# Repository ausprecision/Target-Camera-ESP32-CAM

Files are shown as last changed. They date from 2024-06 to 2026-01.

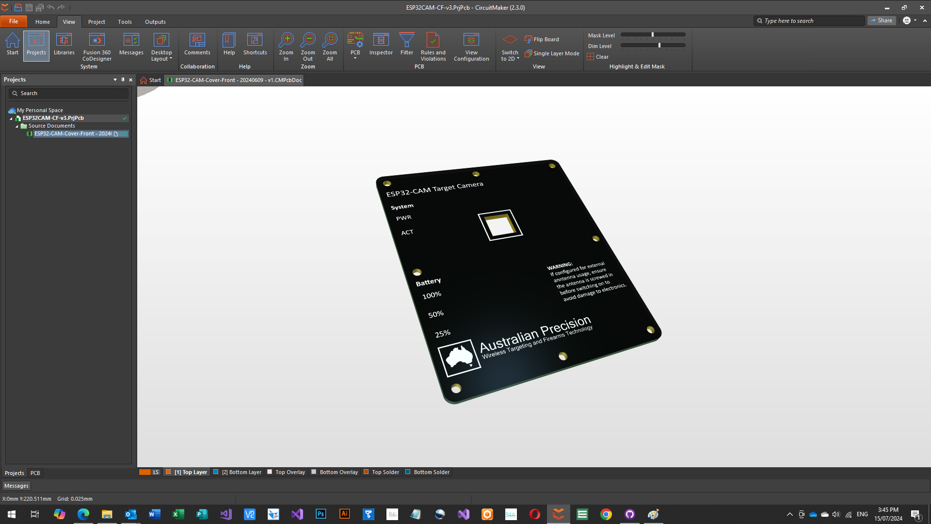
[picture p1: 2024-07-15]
Manufacturing - PCB Design/Image - ESP32-CAM-CF.png

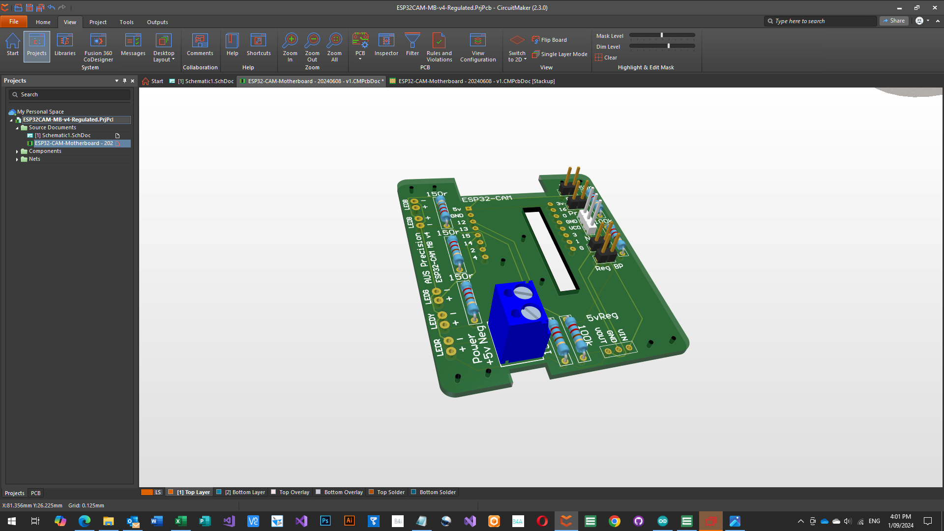
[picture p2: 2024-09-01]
Manufacturing - PCB Design/Image - ESP32-CAM-MB.png

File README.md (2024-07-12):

# Target Camera (ESP32-CAM)
A Wireless Target Camera System based off the ESP32-CAM. A combination of programming languages is used, Arduino IDE for the ESP32-CAM, Windows UWP (Visual Basic) for the client application which also uses an MJPEG library for reading the camera stream. The UWP client application displays the stream and overlays ballistic information.

#### Arduino - IDE code for the ESP32-CAM
- Battery Management - Read ADC (PIN 12) - Prior to WiFi initialization which ties up the ADC inputs on the board.
- Battery Management - Requires a voltage divider, please see the Altium Circuitmaker Schematic and PCB layout.
- OTA / Over The Air Updates - Partition Scheme: "Minimal SPIFFS (1.9MB APP with OTA/190KB SPIFFS).
- SPIFFS partition is small, is primarily used to store config data and a small image file/logo file and favicon.

#### 3D Printing - 3D Printed Parts for the ESP32-CAM Housing/Enclosure
- Main Section - Houses the ESP32-CAM and ESP32-CAM motherboard, light pipes and power switch.
- Battery Section - Houses the battery board and AA battery holder.
- Holder - Anetnna - Part is used for installing the antenna assembly.
- Holder - Nut - Part used for locating/holding the UNC nut for tripods.
- Locating Block - Screwed into the battery board, holds the ESM32-CAM motherboard in place.

Note: Recommend ABS or PETG for 3D Printing due to outdoor use.

#### UWP-Testing-VB - Simple Visual Studio 2022 Application to Read MJPEG Stream from the ESP32-CAM
This application is the testing application for reading the MJPEG stream and displaying it from the ESP32-CAM, please see information below on the required NuGet packages and configuration information. Developed using Microsoft Visual Studio 2022 and Visual Basic.

- NuGet Package - Microsoft.NETCore.UniversalWindowsPlatform - Version 6.1.9
- NuGet Package - MjpegProcessor - Version 1.0.0 - https://github.com/follesoe/MjpegProcessor

Visual Studio 2022 Project Configuration (Visual Basic and C#)
- Target Version - Windows 10, version 2004 (10.0; Build 19041)
- Minimum Version - Windows 10, version 1809 (10.0; Build 17753)

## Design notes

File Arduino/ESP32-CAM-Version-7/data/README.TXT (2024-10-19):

KB Article: AP100001
Product(s): AUS Precision Disk Operating System
Version(s): AP-DOS:1.00
Keyword(s): apdos
Last Modified: 23-SEP-2024
-------------------------------------------------------------------------------
The information in this article applies to:

- AUS Precision AP-DOS Operating System Version 1.00 
-------------------------------------------------------------------------------

SUMMARY
=======

The following information was taken from the AP-DOS 1.00 README.TXT file. This
file is referred to in the AP-DOS1 Concise User's Guide. This file refers to
how AP-DOS interacts with the hardware and software of your ESP32 based target
camera system hardware.

1. HARDWARE COMPATIBILITY WITH AP-DOS
=====================================
1.1 AP-DOS is compatible with any ESP32 based SoC Processor, though is ideally
suited for the ESP32S series processors that are used with various ESP32-CAM
boards from many manufacturers.

1.2 The firmware running AP-DOS uses general purpose input/output (GPIO Pins)
for various functions. These include reading battery levels from the 
analogue to digital converter (ADC) running on the board itself as well as
turning various LED lights on the board on or off.

1.3 Target Camera Systems supplied by AUS Precision run firmware that supports
AP-DOS and also pre-defined GPIO pins for various functions. Other vendors
might be using different GPIO mappings for different hardware functions.

1.4 At the time of this article, the firmware supplied by AUS Precision does
not allow for custom GPIO pin mappings, therefore some AP-DOS functions might
run with problems due to the pin mappings being different. If this is the case
the firmware would need to be manually re-compiled with the correct mappings.

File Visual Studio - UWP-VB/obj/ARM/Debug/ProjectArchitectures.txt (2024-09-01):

C:\Users\david\OneDrive\AUS Precision (GitHub)\Target-Camera-ESP32-CAM\UWP-Testing-VB\UWP-Testing-VB.vbproj;arm

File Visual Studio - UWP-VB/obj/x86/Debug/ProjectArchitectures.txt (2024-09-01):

C:\Users\david\OneDrive\AUS Precision (GitHub)\Target-Camera-ESP32-CAM\Visual Studio - UWP-VB\UWP-Testing-VB.vbproj;x86

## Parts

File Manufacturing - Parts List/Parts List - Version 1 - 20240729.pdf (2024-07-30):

Part Name | Type | Part Detail / Description | QTY Price (EA) Price (Tot.) Used For | Supplier | Supplier Part #
Screw - 4g x 1/2" (2.9 x 12mm) | Fastener | Black Zinc, Countersunk Phillips Self Tapper - ANSI B18.6.4 | 4 | $0.07 | $0.28 | Mounting Main Section to Battery Section | www.boltandnut.com.au | 01C412BZ
Screw - 4g x 1/4" (2.9 x 6.5mm) | Fastener | Black Zinc, Countersunk Phillips Self Tapper - ANSI B18.6.4 | 8 | $0.05 | $0.40 | PCB Face Plate - Mounting to Enclosure (Main Section) | www.boltandnut.com.au | 01C414BZ
Screw - 4g x 1/4" (2.9 x 6.5mm) | Fastener | Black Zinc, Countersunk Phillips Self Tapper - ANSI B18.6.4 | 7 | $0.05 | $0.35 | PCB Battery Cover - Mounting to Enclosure (Battery Section) | www.boltandnut.com.au | 01C414BZ
Screw - 4g x 1/4" (2.9 x 6.5mm) | Fastener | Black Zinc, Countersunk Phillips Self Tapper - ANSI B18.6.4 | 8 | $0.05 | $0.40 | Mounting Main board to Battery Board via Locating Blocks | www.boltandnut.com.au | 01C414BZ
Screw - 4g x 1/4" (2.9 x 6.5mm) | Fastener | Black Zinc, Countersunk Phillips Self Tapper - ANSI B18.6.4 | 4 | $0.05 | $0.20 | Mounting AA Battery Holder to Battery PCB Board | www.boltandnut.com.au | 01C414BZ
3D Printed Part - Locating Blocks | 3D Printed Object | Material ABS/PETG, .STL File Contains All 4 Blocks | 1 | $3.00 | $3.00 | Mounting of ESP32 Main Board to Battery Board | https://mixmakes.net/ | N/A
3D Printed Parts - Enclosure | 3D Printed Object | Material ABS/PETG, Main Section, Battery Section, Cover, Antenna and Nut Holder | 1 | $20.00 | $20.00 All the 3D Printed Parts for the Enclosure/Assembly | https://mixmakes.net/ | N/A
Bivar PLPC1-188 Light Pipe | Misc / Light Pipe | Light Pipe to Allow LED Light to Transmit Light from Inside to Outside Enclosure | 5 | $3.00 | $15.00 Inserted into LED Light Holes on Main Section Enclosure | https://au.mouser.com/ | PLPC1-188
Resistor 150r ohm | Semiconductors | RES 0.5W MTL 150R 1% MINI - 150 Ohm 0.5 Watt Metal Film Resistors | 5 | $0.12 | $0.60 | Soldered onto ESP32 Main Board | www.jaycar.com.au | RR0052
Resistor 100k ohm | Semiconductors | RES 0.5W MTL 100K 1% MINI - 100k Ohm 0.5 Watt Metal Film Resistors | 2 | $0.12 | $0.24 | Soldered onto ESP32 Main Board | www.jaycar.com.au | RR0620
LED - Tower Type (Blue) | LED Lights | LED 2MM DIF TOWER TYPE BLU 780MCD | 2 | $0.75 | $1.50 | Soldered onto ESP32 Main Board, LED Pins Bent at 90 deg. | www.jaycar.com.au | ZD0080
LED - Tower Type (Green) | LED Lights | LED 2MM DIF TOWER TYPE GRN 2200MCD | 1 | $0.95 | $0.95 | Soldered onto ESP32 Main Board, LED Pins Bent at 90 deg. | www.jaycar.com.au | ZD0070
LED - Tower Type (Yellow) | LED Lights | LED 2MM DIF TOWER TYPE YEL 270MCD | 1 | $0.75 | $0.75 | Soldered onto ESP32 Main Board, LED Pins Bent at 90 deg. | www.jaycar.com.au | ZD0050
LED - Tower Type (Red) | LED Lights | LED 2MM DIF TOWER TYPE RED 600MCD | 1 | $0.75 | $0.75 | Soldered onto ESP32 Main Board, LED Pins Bent at 90 deg. | www.jaycar.com.au | ZD0040
IC Socket - 16 Pin (8 Each Side) | Misc / Electronics | SKT IC TIN/G 16PIN/300MIL - Generic IC Socket | 1 | $0.95 | $0.95 | Soldered onto ESP32 Main Board - IC Socket Gets Cut in Half | www.jaycar.com.au | PI6502
2 Way PCB Mount Screw Term. 5mm Pitch | Misc / Electronics | Screw Mount Terminal Block for Providing Power to ESP32 Main PCB Board | 1 | $1.95 | $1.95 | Soldered onto ESP32 Main Board - Switch/Battery Holder Wires Connected | www.jaycar.com.au | HM3172
40 Way 2.54mm Header Pins | Misc / Electronics | HEADER SGL VRT 40WAY P=2.54MM, Cut to Suit Sizes on ES32 Main Board | 1 | $1.45 | $1.45 | Soldered onto ESP32 Main Board, 3 x 2 PINS, 1 x 3 PINS | www.jaycar.com.au | HM3212
SPST Ultra Mini Rocker Switch | Misc / Electronics | Snap in fitting. SPST 250VAC 6A. Black body, black actuator | 1 | $3.10 | $3.10 | Inserted into Main Section, Wires Soldered and Connected to Term. Block | www.jaycar.com.au | SK0975
ESP32-CAM Board + Camera | Main CPU + Camera | ESP32-CAM + OV2490 Camera Module | 1 | $10.00 | $10.00 ESP32-CAM + OV2490 Camera Module, Plugs into ESP32 Main PCB Board | Ali Express | N/A
u.FL Connector (5cm) | Misc / Wireless | u.FL/IPEX Connector to RP-SMA Mount | 1 | $2.50 | $2.50 | Connects to u.FL Connector on ESP32 Board, Mounted on Antenna Holder | Ali Express | N/A
2dbi Antenna (RP-SMA) | Misc / Wireless | 2dbi Wireless Antenna | 1 | $2.00 | $2.00 | External Antenna, Screwed into RP-SMA Enclosure Connector | Ali Express | N/A
4 x AA Battery Holder | Misc / Battery Holder Dimensions of Battery Holder Must Be (1.5cm H x 6.2cm W x 5.8cm L) | 1 | $3.00 | $3.00 | Mounted to Battery Board via 4 x Self Tapping Screws | Ali Express | N/A
PCB - ESP32 Main Board | Printed Circuit Board | PCB - ESP32 Main Board | 1 | $2.25 | $2.25 | Main Board which has the ESP32-CAM Module Inserted into the IC Holder | PCB Way (China) | W601849AS2Y15
PCB - Battery Board | Printed Circuit Board | PCB - Battery Board | 1 | $2.25 | $2.25 | Battery Board which has the 4xAA Battery Holder Screwed to it | PCB Way (China) | W601849AS2Y18
PCB - Cover - Front | Printed Circuit Board | PCB - Cover - Front | 1 | $2.25 | $2.25 | Cover that gets screwed to the Main Section of the Enclosure | PCB Way (China) | W601849AS2Y19
PCB - Cover - Rear/Battery | Printed Circuit Board | PCB - Cover - Rear/Battery | 1 | $2.25 | $2.25 | Cover that gets screwed to the Battery Section of the Enclosure | PCB Way (China) | W601849AS2Y14
| | | | | $78.37

Note: All Prices are in $AUD (Australian Dollars), Subject to change based on currency rate and supply/manufacture costs
Note: Prices do not include shipping fees, they are prices based off minimum quantities from suppliers

Total Cost ($AUD)

### ESP32-CAM Target Camera - Parts List - Version 1 - 29th July 2024

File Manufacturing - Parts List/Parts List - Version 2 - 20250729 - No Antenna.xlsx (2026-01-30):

ESP32-CAM Target Camera - Parts List - Version 1 - 1st February 2025
Part Name | Type | Part Detail / Description | QTY | Price (EA) | Price (Tot.) | Used For | Supplier | Supplier Part #
Screw - 4g x 1/2" (2.9 x 12mm) | Fastener | Black Zinc, Countersunk Phillips Self Tapper - ANSI B18.6.4 | 4 | $0.07 | $0.28 | Mounting Main Section to Battery Section | www.boltandnut.com.au | 01C412BZ
Screw - 4g x 1/4" (2.9 x 6.5mm) | Fastener | Black Zinc, Countersunk Phillips Self Tapper - ANSI B18.6.4 | 8 | $0.05 | $0.40 | PCB Face Plate - Mounting to Enclosure (Main Section) | www.boltandnut.com.au | 01C414BZ
Screw - 4g x 1/4" (2.9 x 6.5mm) | Fastener | Black Zinc, Countersunk Phillips Self Tapper - ANSI B18.6.4 | 7 | $0.05 | $0.35 | PCB Battery Cover - Mounting to Enclosure (Battery Section) | www.boltandnut.com.au | 01C414BZ
Screw - 4g x 1/4" (2.9 x 6.5mm) | Fastener | Black Zinc, Countersunk Phillips Self Tapper - ANSI B18.6.4 | 8 | $0.05 | $0.40 | Mounting Main board to Battery Board via Locating Blocks | www.boltandnut.com.au | 01C414BZ
Screw - 4g x 1/4" (2.9 x 6.5mm) | Fastener | Black Zinc, Countersunk Phillips Self Tapper - ANSI B18.6.4 | 4 | $0.05 | $0.20 | Mounting AA Battery Holder to Battery PCB Board | www.boltandnut.com.au | 01C414BZ
Screw - 4g x 1/4" (2.9 x 6.5mm) | Fastener | Black Zinc, Countersunk Phillips Self Tapper - ANSI B18.6.4 | 4 | $0.05 | $0.20 | Mounting of Nut Holder Base Plate | www.boltandnut.com.au | 01C414BZ
Screw - 4g x 1/4" (2.9 x 6.5mm) | Fastener | Black Zinc, Countersunk Phillips Self Tapper - ANSI B18.6.4 | 4 | $0.05 | $0.20 | Mounting of Antenna Holder Base Plate | www.boltandnut.com.au | 01C414BZ
3D Printed Part - Locating Blocks | 3D Printed Object | Material ABS/PETG, .STL File Contains All 4 Blocks | 1 | $3.00 | $3.00 | Mounting of ESP32 Main Board to Battery Board | https://mixmakes.net/ | N/A
3D Printed Parts - Enclosure | 3D Printed Object | Material ABS/PETG, Main Section, Battery Section, Cover, Antenna and Nut Holder | 1 | $6.00 | $6.00 | All the 3D Printed Parts for the Enclosure/Assembly | https://mixmakes.net/ | N/A
Bivar PLPC1-188 Light Pipe | Misc / Light Pipe | Light Pipe to Allow LED Light to Transmit Light from Inside to Outside Enclosure | 5 | $1.36 | $6.80 | Inserted into LED Light Holes on Main Section Enclosure | https://au.rs-online.com/web/p/led-light-pipes/1749707 | PLPC1-188
Resistor 750r ohm | Semiconductors | RES 0.5W MTL 750R 1% MINI - 150 Ohm 0.5 Watt Metal Film Resistors | 5 | $0.10 | $0.50 | Soldered onto ESP32 Main Board | www.jaycar.com.au | RR0569
Resistor 100k ohm | Semiconductors | RES 0.5W MTL 100K 1% MINI - 100k Ohm 0.5 Watt Metal Film Resistors | 2 | $0.10 | $0.20 | Soldered onto ESP32 Main Board | www.jaycar.com.au | RR0620
LED - Tower Type (Blue) | LED Lights | LED 2MM DIF TOWER TYPE BLU 780MCD | 2 | $0.41 | $0.82 | Soldered onto ESP32 Main Board, LED Pins Bent at 90 deg. | www.jaycar.com.au | ZD0080
LED - Tower Type (Green) | LED Lights | LED 2MM DIF TOWER TYPE GRN 2200MCD | 1 | $0.52 | $0.52 | Soldered onto ESP32 Main Board, LED Pins Bent at 90 deg. | www.jaycar.com.au | ZD0070
LED - Tower Type (Yellow) | LED Lights | LED 2MM DIF TOWER TYPE YEL 270MCD | 1 | $0.41 | $0.41 | Soldered onto ESP32 Main Board, LED Pins Bent at 90 deg. | www.jaycar.com.au | ZD0050
LED - Tower Type (Red) | LED Lights | LED 2MM DIF TOWER TYPE RED 600MCD | 1 | $0.41 | $0.41 | Soldered onto ESP32 Main Board, LED Pins Bent at 90 deg. | www.jaycar.com.au | ZD0040
IC Socket - 16 Pin (8 Each Side) | Misc / Electronics | SKT IC TIN/G 16PIN/300MIL - Generic IC Socket | 1 | $0.40 | $0.40 | Soldered onto ESP32 Main Board - IC Socket Gets Cut in Half | www.jaycar.com.au | PI6502
2 Way PCB Mount Screw Term. 5mm Pitch | Misc / Electronics | Screw Mount Terminal Block for Providing Power to ESP32 Main PCB Board | 1 | $0.95 | $0.95 | Soldered onto ESP32 Main Board - Switch/Battery Holder Wires Connected | www.jaycar.com.au | HM3172
40 Way 2.54mm Header Pins | Misc / Electronics | HEADER SGL VRT 40WAY P=2.54MM, Cut to Suit Sizes on ES32 Main Board | 1 | $0.30 | $0.30 | Soldered onto ESP32 Main Board, 3 x 2 PINS, 1 x 3 PINS | www.jaycar.com.au | HM3212
SPST Ultra Mini Rocker Switch | Misc / Electronics | Snap in fitting. SPST 250VAC 6A. Black body, black actuator | 1 | $2.00 | $2.00 | Inserted into Main Section, Wires Soldered and Connected to Term. Block | www.jaycar.com.au | SK0975
Cardboard Box |  |  | 1 | $5.00 | $5.00
Cardboard |  |  | 1 | $5.60 | $5.60
Business Card |  |  | 3 | $0.10 | $0.30
ESP32-CAM Board + Camera | Main CPU + Camera | ESP32-CAM + OV2490 Camera Module | 1 | $10.00 | $10.00 | ESP32-CAM + OV2490 Camera Module, Plugs into ESP32 Main PCB Board | Ali Express | N/A
4 x AA Battery Holder | Misc / Battery Holder | Dimensions of Battery Holder Must Be (1.5cm H x 6.2cm W x 5.8cm L) | 1 | $3.00 | $3.00 | Mounted to Battery Board via 4 x Self Tapping Screws | Ali Express | N/A
PCB - ESP32 Main Board | Printed Circuit Board | PCB - ESP32 Main Board | 1 | $5.00 | $5.00 | Main Board which has the ESP32-CAM Module Inserted into the IC Holder | PCB Way (China) | W601849AS2Y15
PCB - Battery Board | Printed Circuit Board | PCB - Battery Board | 1 | $5.00 | $5.00 | Battery Board which has the 4xAA Battery Holder Screwed to it | PCB Way (China) | W601849AS2Y18
PCB - Cover - Front | Printed Circuit Board | PCB - Cover - Front | 1 | $5.00 | $5.00 | Cover that gets screwed to the Main Section of the Enclosure | PCB Way (China) | W601849AS2Y19
PCB - Cover - Rear/Battery | Printed Circuit Board | PCB - Cover - Rear/Battery | 1 | $5.00 | $5.00 | Cover that gets screwed to the Battery Section of the Enclosure | PCB Way (China) | W601849AS2Y14
Total Cost ($AUD) |  |  |  |  | $68.24
Note: All Prices are in $AUD (Australian Dollars), Subject to change based on currency rate and supply/manufacture costs
Note: Prices do not include shipping fees, they are prices based off minimum quantities from suppliers

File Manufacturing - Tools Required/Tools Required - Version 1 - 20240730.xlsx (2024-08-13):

ESP32-CAM Target Camera - Tools Required - Version 1 - 30th July 2024
Tool / Accessory / Consumable Name | Type | Detail / Description / Note | QTY | Price (EA) | Price (Tot.) | Used For | Supplier | Supplier Part #
Drill Press or Cordless Drill | Tool / Device |  | 4 | $0.07 | $0.28 | Mounting Main Section to Battery Section | www.boltandnut.com.au | 01C412BZ
Soldering Iron (with fine tip) | Tool / Device
Phillips Head Screw Driver | Tool / Device |  | 1 | $3.00 | $3.00 | Mounting of ESP32 Main Board to Battery Board | https://mixmakes.net/ | N/A
 |  |  | 1 | $20.00 | $20.00 | All the 3D Printed Parts for the Enclosure/Assembly | https://mixmakes.net/ | N/A
Side Cutters (Decent Quality) | Tool / Device
Nose Pliers / Needle Nose Pliers | Tool / Device |  | 5 | $3.00 | $15.00 | Inserted into LED Light Holes on Main Section Enclosure | https://au.mouser.com/ | PLPC1-188
3D Printer | Tool / Device
DC Power Supply | Tool / Device |  | 1 | $0.95 | $0.95 | Soldered onto ESP32 Main Board, LED Pins Bent at 90 deg. | www.jaycar.com.au | ZD0070
Digital Multimeter | Tool / Device |  | 1 | $0.75 | $0.75 | Soldered onto ESP32 Main Board, LED Pins Bent at 90 deg. | www.jaycar.com.au | ZD0050
FTDI Programmer Board | Accessory
USB A to USB Mini Cable | Accessory
Accessory - Countersink Tool | Accessory |  | 8 | $0.05 | $0.40 | PCB Face Plate - Mounting to Enclosure (Main Section) | www.boltandnut.com.au | 01C414BZ
Accessory - 2.5mm Drill Bit | Accessory |  | 7 | $0.05 | $0.35 | PCB Battery Cover - Mounting to Enclosure (Battery Section) | www.boltandnut.com.au | 01C414BZ
Accessory - 3.0mm Drill Bit | Accessory |  | 8 | $0.05 | $0.40 | Mounting Main board to Battery Board via Locating Blocks | www.boltandnut.com.au | 01C414BZ
 |  |  | 4 | $0.05 | $0.20 | Mounting AA Battery Holder to Battery PCB Board | www.boltandnut.com.au | 01C414BZ
Solder (Spool) | Consumable |  | 5 | $0.12 | $0.60 | Soldered onto ESP32 Main Board | www.jaycar.com.au | RR0052
ABS or PETG Filament (500g) | Consumable |  | 2 | $0.75 | $1.50 | Soldered onto ESP32 Main Board, LED Pins Bent at 90 deg. | www.jaycar.com.au | ZD0080
Jumper Wire | Consumable |  | 1 | $0.75 | $0.75 | Soldered onto ESP32 Main Board, LED Pins Bent at 90 deg. | www.jaycar.com.au | ZD0040
Sandpaper - Fine Grit | Consumable |  | 2 | $0.12 | $0.24 | Soldered onto ESP32 Main Board | www.jaycar.com.au | RR0620
POSCA Marker Pen (Black) | Consumable
 |  |  | 1 | $0.95 | $0.95 | Soldered onto ESP32 Main Board - IC Socket Gets Cut in Half | www.jaycar.com.au | PI6502
 |  |  | 1 | $1.95 | $1.95 | Soldered onto ESP32 Main Board - Switch/Battery Holder Wires Connected | www.jaycar.com.au | HM3172
 |  |  | 1 | $1.45 | $1.45 | Soldered onto ESP32 Main Board, 3 x 2 PINS, 1 x 3 PINS | www.jaycar.com.au | HM3212
 |  |  | 1 | $3.10 | $3.10 | Inserted into Main Section, Wires Soldered and Connected to Term. Block | www.jaycar.com.au | SK0975
 |  |  | 1 | $10.00 | $10.00 | ESP32-CAM + OV2490 Camera Module, Plugs into ESP32 Main PCB Board | Ali Express | N/A
 |  |  | 1 | $2.50 | $2.50 | Connects to u.FL Connector on ESP32 Board, Mounted on Antenna Holder | Ali Express | N/A
 |  |  | 1 | $2.00 | $2.00 | External Antenna, Screwed into RP-SMA Enclosure Connector | Ali Express | N/A
 |  |  | 1 | $3.00 | $3.00 | Mounted to Battery Board via 4 x Self Tapping Screws | Ali Express | N/A
 |  |  | 1 | $2.25 | $2.25 | Main Board which has the ESP32-CAM Module Inserted into the IC Holder | PCB Way (China) | W601849AS2Y15
 |  |  | 1 | $2.25 | $2.25 | Battery Board which has the 4xAA Battery Holder Screwed to it | PCB Way (China) | W601849AS2Y18
 |  |  | 1 | $2.25 | $2.25 | Cover that gets screwed to the Main Section of the Enclosure | PCB Way (China) | W601849AS2Y19
 |  |  | 1 | $2.25 | $2.25 | Cover that gets screwed to the Battery Section of the Enclosure | PCB Way (China) | W601849AS2Y14
Total Cost ($AUD) |  |  |  |  | $78.37
Note: All Prices are in $AUD (Australian Dollars), Subject to change based on currency rate and supply/manufacture costs
Note: Prices do not include shipping fees, they are prices based off minimum quantities from suppliers

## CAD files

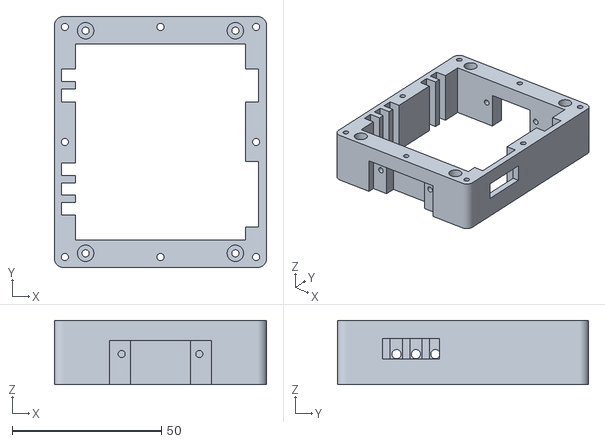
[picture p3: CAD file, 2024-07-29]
Manufacturing - 3D Printing/ESP32 Target Camera - Main Section v3 - 20240725.stl
71.0 x 84.0 x 21.5

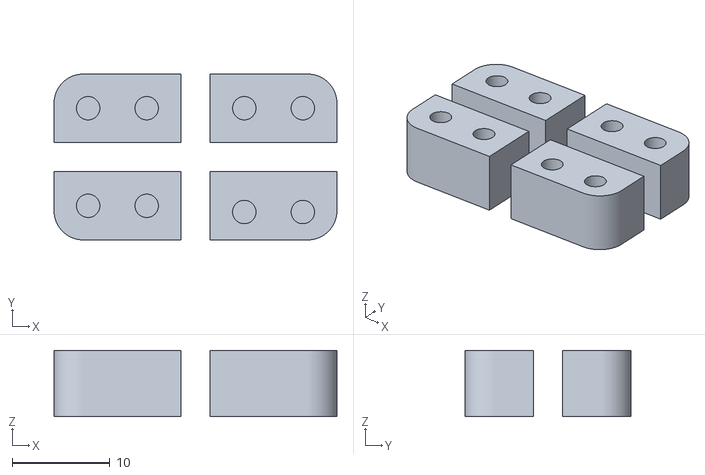
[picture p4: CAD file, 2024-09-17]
Manufacturing - 3D Printing/Locating Blocks x 4 - Version 1 - 6.8mm - 20240729.stl
29.0 x 17.0 x 6.80

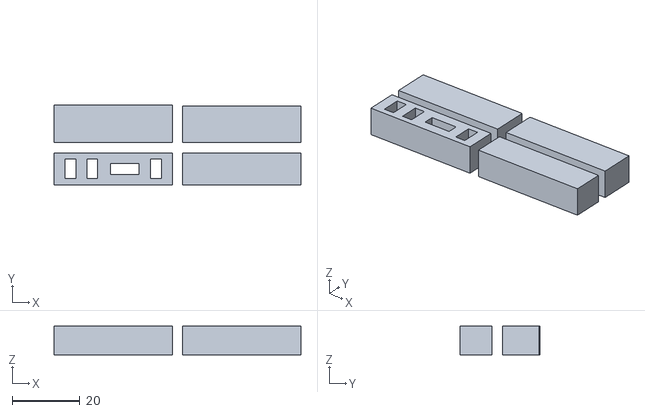
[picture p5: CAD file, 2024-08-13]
Manufacturing - 3D Printing/Tool - Header Pin Holder for Solder - Version 1 - 20240730.stl
73.0 x 23.6 x 8.50

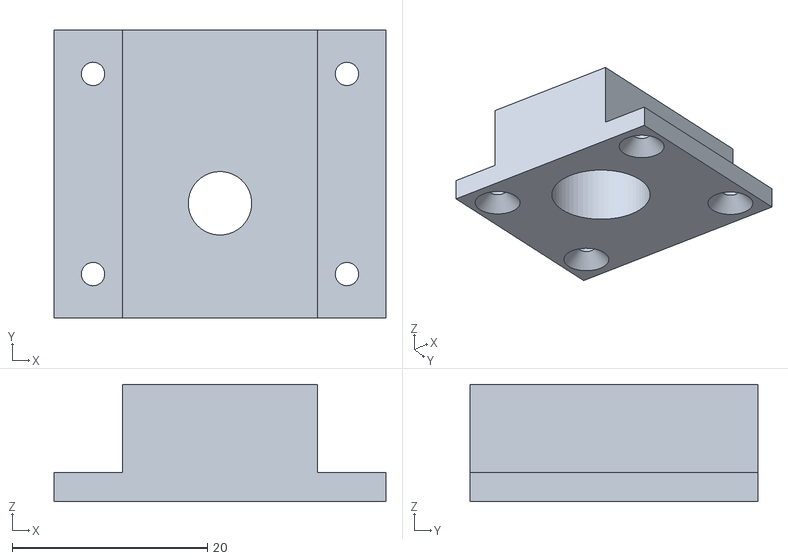
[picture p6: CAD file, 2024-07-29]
Manufacturing - 3D Printing/ESP32 Target Camera - Holder - Antenna v2 - 20240525.stl
34.0 x 29.5 x 12.0

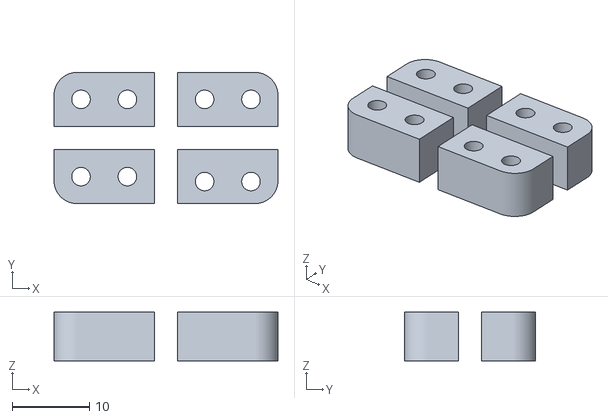
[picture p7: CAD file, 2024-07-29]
Manufacturing - 3D Printing/Locating Blocks x 4 - Version 1 - 6.3mm - 20240729.stl
29.0 x 17.0 x 6.30

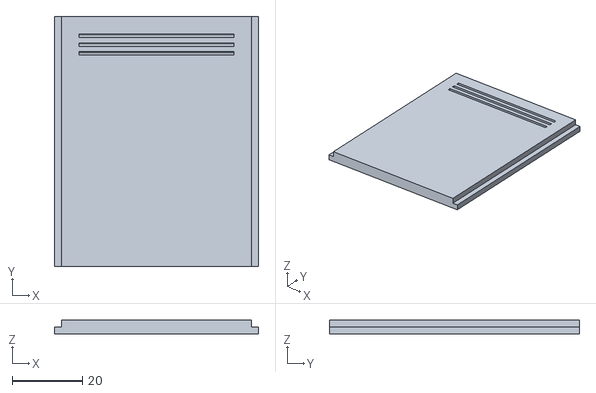
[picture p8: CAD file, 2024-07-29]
Manufacturing - 3D Printing/ESP32 Target Camera - Slide Cover v1 - 20240613.stl
58.0 x 71.0 x 4.00

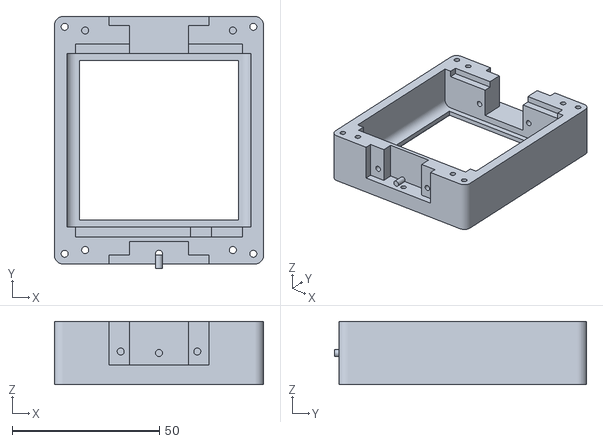
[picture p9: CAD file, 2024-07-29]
Manufacturing - 3D Printing/ESP32 Target Camera - Battery Section v4 - 20240525.stl
71.0 x 85.5 x 21.5

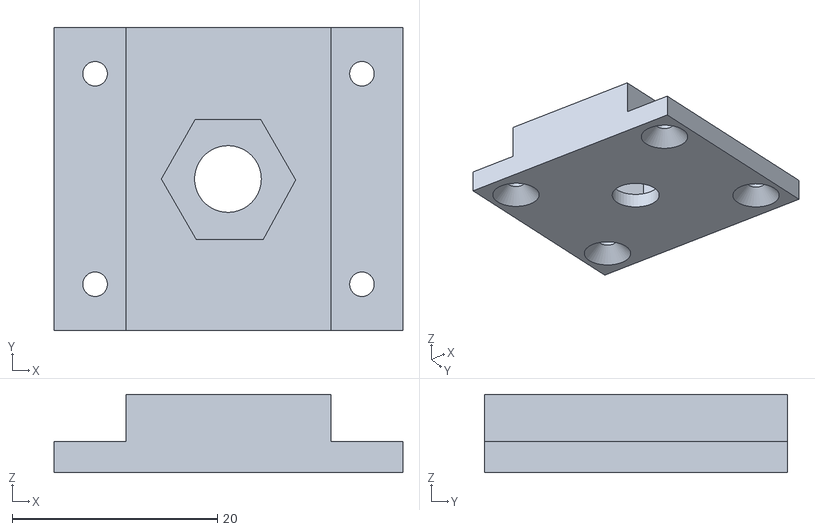
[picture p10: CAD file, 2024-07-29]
Manufacturing - 3D Printing/ESP32 Target Camera - Holder - Nut Holder v4 - 20240525.stl
34.0 x 29.5 x 7.60

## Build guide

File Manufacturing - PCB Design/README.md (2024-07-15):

# Manufacturing of PCB Boards for the ESP32-CAM Target Camera

FAB-ESP32CAM-CB: Back Cover for the target camera, blank PCB cutout/faceplate, no copper.
FAB-ESP32CAM-CF: Front Cover for the target camera, blank PCB cutout/faceplate, no copper.
FAB-ESP32CAM-MB: PCB Mainboard for the ESP32-CAM, voltage regulator, LED's and connectors.

FAB-AA-Battery-Board-V1: Blank PCB with holes for mounting a 4xAA Battery Holder.

All PCB's have been designed in Altium Circuit Maker, the .ZIP files contain gerber and drill hole information.

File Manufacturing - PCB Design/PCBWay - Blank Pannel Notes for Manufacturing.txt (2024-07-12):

PCB is just a blank panel for an enclosure. No electronics, no tracks, etc. The PCB is essentially a faceplate.

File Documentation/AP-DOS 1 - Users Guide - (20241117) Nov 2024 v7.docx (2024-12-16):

Concise User’s Guide

November
2024

AP-DOS1

Operating System

AUS Precision

Date of Publication: 17th November 2024

Information in this document is subject to change without notice. Companies, names and data used in examples herein are fictious unless otherwise noted. No part of this document may be reproduced or transmitted in any form or by any means, electronic or mechanical, for any purpose, without the express written permission of Australian Precision Firearms Technologies and Wildlife Management.

© 2024 Australian Precision Firearms Technologies and Wildlife Management. All rights reserved.

Printed in Australia.

Table of Contents

# Welcome

Welcome to the AUS Precision AP-DOS operating system. AP-DOS 1 includes features that are described later in this introduction. If this is your first time using AP-DOS, refer to the chapter “Getting Started’ for information about how to use the operating system.

## About Your AP-DOS Documentation

AP-DOS documentation consists of the AUS Precision AP-DOS Concise User’s
Guide, AP-DOS command line help, and several other online documents.

This guide includes information for inexperienced users and some advanced topics for users familiar with AP-DOS. AP-DOS Help is an online reference to AP-DOS commands. The reference includes information about how to type commands and their parameters and switches, notes about commands, and examples of how to use commands.

After you’ve connected to AP-DOS, you can display the AP-DOS Help table of contents by typing help at the command prompt and then pressing ENTER. You can also get information about a command by typing help and the name of the command at the command prompt.

When connecting to this version of AP-DOS, you will find the following text files in the directory that contains your AP-DOS files: the README.TXT file, which provides information about how AP-DOS interacts with the hardware and software, and the NETWORKS.TXT file, which provides information about making your network compatible with this version of AP-DOS.

## Features of AP-DOS 1

AP-DOS has many features that will allow you control and operate your
ESP32-CAM target camera from the command line environment:

- Display contents of the disk drive which shows all the files stored locally, these include configuration files, text files and images and graphics used by the internal web server. Used and available disk space is also displayed.
- Ability to get or set various camera settings during runtime, these include camera resolutions, jpeg compression, vertical flip, horizontal flip, camera clock speed and automatic exposure correction.
- Wireless configuration allows you to get or set Wi-Fi options including the channel, password, wireless network name (SSID) along with the password for the network and transmission power.
- Ability to change the CPU clock speed from 240MHz to 160MHz or even down to 80MHz. Changing the CPU clock speed can improve battery performance but might impact upon the internal system timers.
- Control of the on-board LED’s, these can be turned off or on individually or as a whole group. Turning off the LED’s can also assist with extending battery life of the system.
- System debug information can be enabled and displayed to the terminal. The information displayed is the serial output debug information from the firmware running on the ESP32-CAM.
- The system can also be rebooted remotely via the command line environment, this is helpful if the webserver, desktop or mobile applications stop responding to commands over those interfaces.

## Conventions

This guide uses document and keyboard conventions to help you locate and identify information.

### Document Conventions

To help you locate and interpret information easily, this guide uses consistent visual cues and a standard key combination format. These conventions are explained as follows

This Represents

bold Commands and the switches that follow them. You must type commands and their switches exactly as they appear.

italic Placeholders that represent information you must provide.
Italic type also signals a new term. An explanation precedes or follows the italicized term.

ALL CAPITALS The names of computers, printers, directories, and files.

AUS Precision documentation uses the term AP-DOS to refer to the AP-DOS, Microsoft® MS-DOS and IBM® Personal Computer DOS operating systems.

### Keyboard Conventions

Key combinations and key sequences appear in the following format:

Notation Represents

KEY1+KEY2 Hold down the first key while you press the second key. For example, “Press CTRL+C” means that you press CTRL and hold it down while you press C.

C H A P T E R 1

# Getting Started

AUS Precision ESP32-CAM Target Camera Systems are sold with the AP-DOS operating system installed. However, if your Target Camera System doesn’t have the AP-DOS 1 operating system installed or you have built your own system based off an ESP32 SoC, you will need to flash the firmware onto the chip.

## Installing the Firmware - Requirements

You will require the following to install the firmware and associated data files:

- Arduino IDE - arduino-1.8.16-windows
- Install the ESP32 Boards Library - esp32 2.0.16 (by Espressif Systems)
- Install the ESP32 Data Upload Tool - ESP32FS-1.0.zip
- AUS Precision GitHub Page – Arduino Code
- A serial programming cable with jumper wires
- Optional: A ESP32-CAM Motherboard with Micro USB Connector
- Optional: A USB A to Micro B Cable for the ESP32-CAM Motherboard

## Installing the Firmware - Procedure

From the Arduino IDE, open the sketch from the downloaded Arduino Code from the AUS Precision GitHub Page. Make sure the ESP32-CAM is connected to your desktop computer (either via the serial programming cable or via the USB cable from the optional ESP32-CAM Motherboard).

- Select the correct com port (Tools -> Port)
- Upload the sketch from the Arduino IDE (Sketch -> Upload)
- After this is completed, reset the board (disconnect the cable, reconnect)
- Upload the Associated Data Files (Tools -> ESP32 Sketch Data Upload)

C H A P T E R 2

# AP-DOS Basics

This chapter explains the basics of using AP-DOS 1. The first section of this chapter is a tutorial. The section explains in more detail some of the concepts described in the tutorial and provides information about using AP-DOS Help.

## Learning AP-DOS Basics - A Tutorial

By following the procedures in this section, you will learn how to connect to an AP-DOS session, view the contents of the root directory, delete files and execute commands to control the AUS Precision Target Camera hardware.

### Connect to AP-DOS via Telnet

To connect to AP-DOS, you need to be connected to your ESP32 based target camera system’s wireless network. Once connected, you will then need to open the Telnet application on your computer or mobile device. The default Telnet address for connecting to AP-DOS is 192.168.4.1.

### The Command Prompt

When you first connect to the AP-DOS session, you will see some information flash by. When the information stops scrolling past, you will see the following:

C:\>

This is called the command prompt. The flashing underscore next to the command prompt is called the cursor. The cursor shows where the command you type will appear.

### Typing a Command

This section explains how to type a command at the command prompt. After typing a command, you must press ENTER.

- To type a command at the command prompt
1. Type the following command at the command prompt (you can type the command in either uppercase or lowercase letters): ver
2. Press ENTER

The following message appears on your screen:

AP-DOS version 1.00

The ver command displays the version number of AP-DOS. If you see the message “Bad command or file name,” a mistake might have been made, so try typing the command again.

### Viewing the Contents of the Root Directory

In this section, you will view the contents of the root directory using the dir command. The dir command stands for “directory.”

- To view the contents of the root directory
- Type the following command at the command prompt: dir A list similar to the following appears:

Volume in drive C is AP-DOS_1

Volume Serial Number is ESP32-SPIFFS

Directory of C:\

FAVICON ICO 15,406 08-21-24 4:11p

CFG-RES INI 16 08-21-24 4:11p

CPU INI 5 08-21-24 4:11p

WIFIPASS INI 12 08-21-24 4:11p

WIFISSID INI 10 08-21-24 4:11p

5 file(s) 15,449 bytes

93,372 bytes free

This is called a directory list. A directory list is a list of all the files that a directory contains. In this case, you see all the files and directories in the main or root directory of your drive.

### Deleting Files

This section explains how to delete or remove a file that you no longer want on your disk. To delete a file, you will use the del command. The del command stands for “delete.”

- To delete the MISC.TXT file
1. Delete the MISC.TXT file by typing the following at the command prompt: del misc.txt
2. To confirm that you deleted the file successfully, type the following at the command prompt: dir

The MISC.TXT file should no longer appear in the directory list.

### Viewing Files

In this section, you will view the contents of a file using the type command. This command outputs the contents of a file onto the screen. Only files that contain text will be output to the screen, these include .TXT and .INI files.

- To view the contents of a file
1. View the README.TXT file by typing the following at the command prompt: type readme.txt
2. The contents of the README.TXT file will then be displayed out onto the screen. If there are more than 25 lines of text to be displayed a prompt of “-- More --" will be displayed. If this is displayed, simply press ENTER to display the next 25 lines of text.

## How AP-DOS Organizes Information

The preceding tutorial introduced the commands you will most often use to find and move information. It also introduced some important terms – file, directory, and drive that you need to understand to use AP-DOS effectively. This section provides more information about these terms and explains how AP-DOS organizes information.

### Files

A file is the primary unit of storage on your system. A file enables AP-DOS to distinguish one collection of information from another. Every file has a name, which generally indicates what type of information the file contains.

The files on your system come from various sources. Some files come with
AP-DOS, while others come from other applications such as a word processor. These files contain code and other information that is necessary to make your system and system applications run.

### Directories

AP-DOS does not support directories with the current file system being SPIFFS. There is one main directory called the root directory. The root directory is the starting point from which all files are stored. The root directory does not have a name. Instead, it is represented by a backslash (\). When the root directory is the current directory, the command prompt appears to the following: C:\>

### Drives

Just as the root directory is a group of files, a drive, which is always represented by a drive letter, is just a group of files. Drives are usually associated with a piece of hardware called a disk. A disk can be anything on which data is stored.

Your first drive is called drive C. The following command prompt indicates
that drive C is the current drive and that the root directory, represented by a
backslash (\), is the current directory: C:\>

## Naming Files

Every file must have a name. The following list summarizes the rules for naming files. File names:

- Can be up to eight characters long. In addition, you can include and extension up to three characters long.
- Are not case-sensitive. It does not matter whether you use uppercase or lowercase letters when you type them.
- Can contain only the letters A through Z, the numbers 0 through 9, and
- Cannot contain spaces, commas, backslashes, or periods (except the period that separates the name from the extension).
- Cannot be identical to the name of another file in the same directory.

## Using Extensions

Most filenames have two parts: the name and the extension. These parts are separated by a period. The name (before the period) can be up to eight characters long and should reflect the contents of the file. The extension (after the period) can be up to three characters long.

The following are examples of commonly used extensions for filenames:

- .ICO, .JPG, .GIF These extensions are commonly used in graphical applications. These files exist on the AP-DOS file system and are accessed by the webserver running on the target camera system.
- .INI This extension is used for files that contain configuration information.
- .TXT This extension is commonly used for unformatted text files.

Many applications name files using an extension that is unique to that application and might only be able to be read by that application.

## Getting Help

There are type types of online help for AP-DOS commands: Using Online Help from the AUS Precision website which is a complete online command reference library for AP-DOS commands, including syntax, notes and examples; and Command-Line Help, which displays the syntax of a command without leaving the command line.

## Using Online Help

AP-DOS Online Help provides an online reference to AP-DOS commands. You can access AP-DOS Online Help by visiting the AP-DOS web page on the AUS Precision website. From there it will display a table of contents, and you can choose a topic from it; or you can bypass the table of contents and display information about a specific command.

## Using Command-Line Help

You can get information about the syntax of a command without starting an online web browser session to the AUS Precision website. This information is less detailed than the Online AP-DOS Help and appears directly at the command prompt.

- To display the syntax of a command
- At the command prompt, type the name of the command followed by a space and the /? Switch. For example, to view the syntax of the dir command, type the following at the command prompt dir /?

C H A P T E R 3

# Accessing Your System

AP-DOS 1 has built in programs that you can use to manage and configure your target camera system. You can access AP-DOS from any Microsoft, Apple, or Android device. Additionally, there are desktop applications on these platforms that interact with the functions of AP-DOS via a graphical user interface.

## Microsoft Windows

By default, Microsoft Windows does not have telnet enabled, therefore you will need to enable telnet under programs and features in Microsoft Windows version 7 and higher to connect to AP-DOS on your ESP32 based target camera system. There is also the dedicated AUS Precision Target Camera app available from the Microsoft Store along with the AUS Precision Management System (APMS).

## Apple iOS

You can connect to AP-DOS via any Apple device running Apple iOS using a telnet app from the Apple App Store. Additionally, you can also install the AUS Precision Target Camera app, or AUS Precision Management System (APMS). These dedicated apps allow you to access, manage and view your ESP32 based target camera system.

## Android OS

As with the Apple iOS Management, you can also use any telnet application available on the Google Play Store to connect to AP-DOS on your ESP32 based target camera system. There is also the AUS Precision Target Camera app as well as the AUS Precision Management System (APMS) available for Android OS.

C H A P T E R 4

# Configuring Your System

Your ESP32-CAM based target camera can be configured to specific requirements of its intended use and overall distance to target. Adjusting these settings allows for fine tuning of the system in its operating environment.

## Camera Settings

Adjusting the camera settings can have an impact upon many factors, the main being the frame rate. At greater distances, the bandwidth reduces and so does the frame rate. Adjusting the resolution and picture quality can assist with this.

## CPU Settings

By adjusting the CPU of the ESP32-CAM, you can improve battery runtime, however this may introduce system stability issues with internal clock timers and the system might become unstable.

## Wireless Settings

You can adjust various wireless settings that will improve performance and transmission distance, these settings include the wireless channel as well power of the transmitted signal.

C H A P T E R 5

# Command Line Reference

This chapter covers all the commands available within AP-DOS from the command line. There are many commands, some are simple, while others have detailed parameter options associated with them.

### List of Available Commands

CAMERA - Camera Configuration and management
CPU - Setting of the CPU clock speed
DEL - Deletion of a file
DIR - Displays the files stored on the camera system
EXIT - Terminates the current AP-DOS session
HELP - Displays a list of the available commands in AP-DOS
REBOOT - Reboots the ESP32-CAM target camera system
TYPE - Displays the contents of a specified text file
VER - Displays the current version of AP-DOS
VOL - Displays the disk volume information
WIRELESS - Wireless Configuration and management

### CAMERA

Provides access to the camera configuration by either getting the configuration parameter for a camera feature or setting the parameter for the camera.

Syntax
CAMERA GET

Displays the current camera configuration including resolution, camera clock speed, automatic exposure control, vertical and horizontal flip and image quality.

Syntax
CAMERA SET RES [VGA|SVGA|XGA|HD|SXGA|UXGA]

Parameters
[VGA|SVGA|XGA|HD|SXGA|UXGA]
Sets the camera resolution. Different resolutions have different frame rates depending on wireless transmission distance and signal strength.

Syntax
CAMERA SET XCLK [8-20]

Parameters
[8-20]
Sets the clock speed of the camera. This can improve camera framerate and picture quality, some OV2640 camera revisions might need fine tuning.

Syntax
CAMERA SET AEC2 [ON|OFF]

Parameters
[ON|OFF]
Turns the Automatic Exposure Control on or off.

Syntax
CAMERA SET [VFLIP|HFLIP] [ON|OFF]

Parameters
[VFLIP|HFLIP] [ON|OFF]
Flips the camera pixels horizontally ON or OFF, same for vertical.

Syntax
CAMERA SET QUALITY [10-90]

Parameters
[10-90]
Numerical value, sets the quality of the MJPEG stream, the lower the setting, the more pixelation and degradation of the image. Lower settings will improve streaming performance at greater distances due to lower bandwidth requirements.

### CPU

Provides access to set the current ESP32 CPU clock speed. By changing the CPU clock speed from the default of 240Mhz, it may cause stability issues with internal timers that the system uses to run tasks.

Syntax
CPU GET

Gets the current CPU clock speed in Mhz.

Syntax
CPU SET [240|160|80]

Parameters
[240|160|80]
Sets the ESP32 CPU clock speed in Mhz. Can improve battery runtime but may impact upon system stability and internal timers for tasks.

### DEL

Deletes a file from the file system. Enter the filename after the DEL command. No wildcards or partial filenames are supported. The full name and extension of the file must be entered. Only deletes one file at a time.

### DIR

Displays the contents of the root directory. This will display a list of files, their sizes, the date and time that the file was created along with used and total free disk space.

### EXIT

Exit will terminate the current Telnet session to AP-DOS.

### HELP

Displays a list of all the available command for AP-DOS and a brief explanation of what each command does.

### REBOOT

Reboots the ESP32 after 5 seconds from when the command was executed.

### TYPE

Displays the output of .TXT and .INI files on the system to the screen. It is not designed for displaying files that have binary / non-text data. Enter the filename after the command. Displays 24 lines of text, prompting for more.

### VER

Displays the AP-DOS version number.

### VOL

Displays the ESP32 SPIFFS volume information for the disk drive.

### WIRELESS

This command can be used to get the current wireless (Wi-Fi) configuration of the ESP32 and can also set various Wi-Fi settings such as transmission (TX) power along with wireless SSID name and Wireless Password for the Wi-Fi network created by the ESP32. Before changing any settings, make sure you consult your local authority on any wireless regulations.

Syntax
WIRELESS GET

Displays the current wireless configuration of the camera system including wireless channel, mode, power and password.

Syntax
WIRELESS SET CHANNEL [0-11]

Parameters
[0-11]
Sets the Wireless Channel Number from 0 to 11. Some countries restrict which wireless channels you can use across the 2.4 GHz spectrum. Changing the channel might improve performance if other channels are congested.

Syntax
WIRELESS SET NAME [SSID]

Parameters
[SSID]
The SSID is the wireless network name of the ESP32-CAM target camera system. The wireless network name can only be 8 characters in length.

Syntax
WIRELESS SET PASSWORD [PASSWORD]

Parameters
[PASSWORD]
Set the password of the wireless network. The password has a maximum length of 8 characters and can be a combination upper case or lowercase letters along with numbers. No special characters are permitted.

Syntax
WIRELESS SET POWER [1-10]

Parameters
[1-10]
This sets the transmission (TX) power of the onboard wireless chip on the ESP32-CAM. The default is 10, being maximum power. The output power is measured in dBm. Check with your local authority on transmission power limits before adjusting this setting.

C H A P T E R 6

# Diagnosing and Solving Problems

Most problems can typically be resolved by rebooting or restarting all of the devices you are using including the ESP32-CAM and any client device that needs to interact with it.

## Problems Connecting to AP-DOS

Prior to connecting to AP-DOS, ensure you are connected to the correct wireless network that the ESP32-CAM is broadcasting. Also ensure that the client device trying to connect does not have any firewall restrictions that may block the ports used by the system and the correct firewall profile is applied for your security requirements.

## Firmware Stability Issues on the ESP32-CAM

The AP-DOS Operating System is part of the firmware loaded onto the
ESP32-CAM. The firmware is regularly updated in release branches of “BETA” and “STABLE”. Running older versions of the firmware might have bugs that need to be addressed, always make sure you have the latest firmware loaded onto the system. The latest firmware is available from the AUS Precision GitHub site.

# Support

Support for AP-DOS 1 is provided by AUS Precision directly along with certified partners and developers. AUS Precision also offers direct support to those customers that have purchased their ESP32 based target camera systems. The support details are listed below.

## Australia and New Zealand

Phone: +614 1270 1411
Website: www.ausprecision.com.au
Email: support@ausprecision.com.au

## United States of America

Phone: +1 (865) 1000 1000
Website: www.ausprecision.com
Email: support@ausprecision.com

## International Support

Phone: +1 (865) 1000 1000
Website: www.ausprecision.com
Email: international@ausprecision.com

Getting Started 5

AP-DOS Basics 11

10 AP-DOS Basics

12 AP-DOS Basics

14 AP-DOS Basics

AP-DOS Basics 16

18 Accessing Your System

Configuring Your System 20

Command Line Reference 19

Diagnosing and Solving Problems 22

Command Line Reference 21

21 Command Line Reference

24 Diagnosing and Solving Problems

22 Command Line Reference

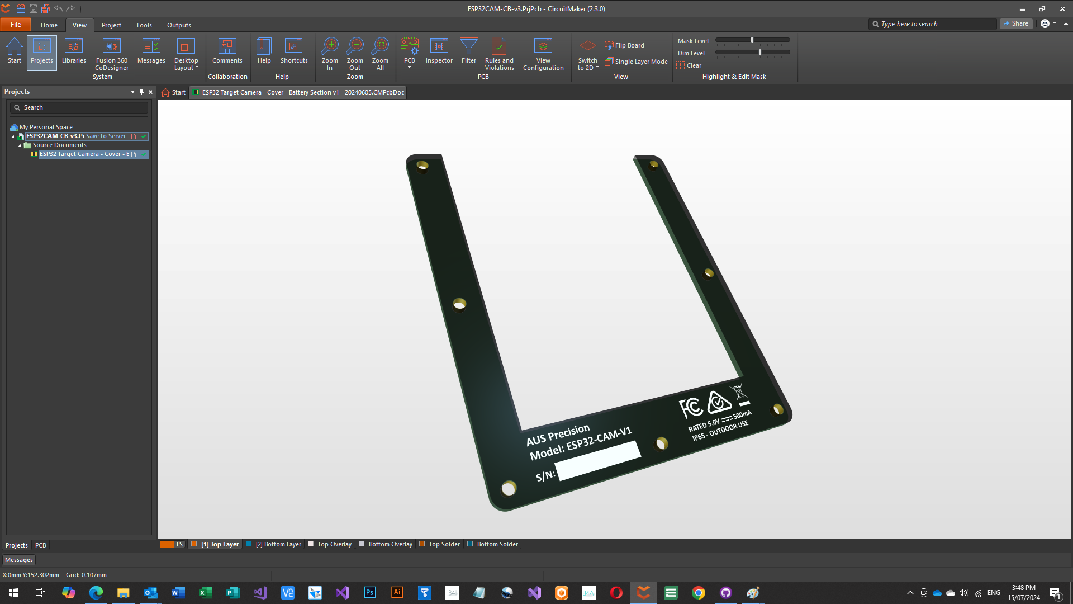
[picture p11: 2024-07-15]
Manufacturing - PCB Design/Image - ESP32-CAM-CB.png

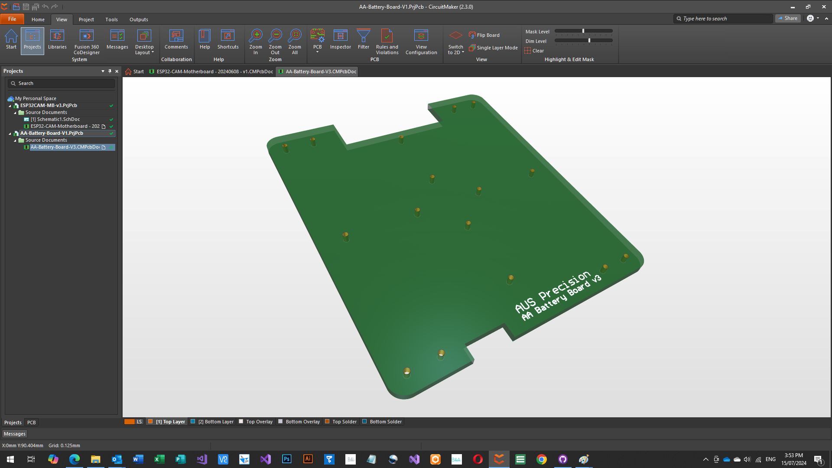
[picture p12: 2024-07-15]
Manufacturing - PCB Design/Image - AA-Battery-Board-V3.png

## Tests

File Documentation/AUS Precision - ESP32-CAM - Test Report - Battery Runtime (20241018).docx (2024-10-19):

ESP32-CAM – Battery Runtimes 18th October 2024

Generic ESP32-CAM - Variant 1 | | | | Generic ESP32-CAM - Variant 2 | | | | AI Thinker ESP32-CAM

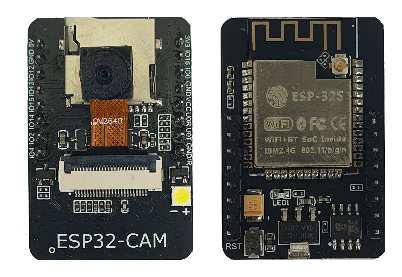
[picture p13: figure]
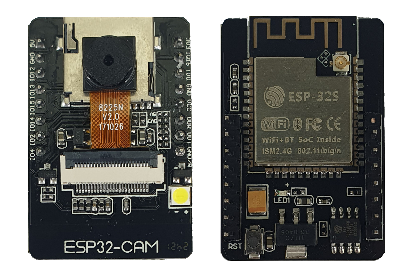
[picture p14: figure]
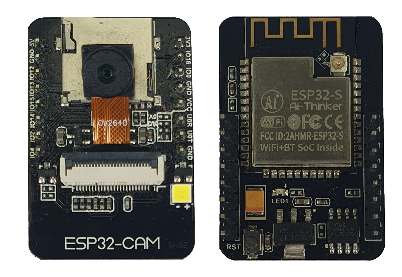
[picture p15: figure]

Voltage | ADC | Runtime | | Voltage | ADC | Runtime | | Voltage | ADC | Runtime
6.10v | 1949 | 0.00 HRS | | 6.09v | 1924 | 0.00 HRS | | 6.25v | 2051 | 0.00 HRS
5.56v | 1697 | 0.50 HRS | | 5.62v | 1698 | 0.50 HRS | | 5.70v | 1795 | 0.50 HRS
5.32v | 1602 | 1.00 HRS | | 5.35v | 1587 | 1.00 HRS | | 5.45v | 1673 | 1.00 HRS
5.18v | 1553 | 1.50 HRS | | 5.19v | 1525 | 1.50 HRS | | 5.34v | 1617 | 1.50 HRS
5.05v | 1504 | 2.00 HRS | | 5.05v | 1480 | 2.00 HRS | | 5.22v | 1574 | 2.00 HRS
4.90v | 1466 | 2.50 HRS | | 4.90v | 1438 | 2.50 HRS | | 5.10v | 1534 | 2.50 HRS
4.75v | 1437 | 3.00 HRS | | 4.78 | 1408 | 3.00 HRS | | 5.00v | 1500 | 3.00 HRS
4.64v | 1408 | 3.50 HRS | | 4.68 | 1381 | 3.50 HRS | | 4.90v | 1472 | 3.50 HRS
4.54v | 1378 | 4.00 HRS | | 4.58 | 1355 | 4.00 HRS | | 4.82v | 1449 | 4.00 HRS
4.40v | 1355 | 4.50 HRS | | 4.44v | 1325 | 4.50 HRS | | 4.73v | 1422 | 4.50 HRS
4.20v | 1316 | 5.00 HRS | | 4.32v | 1297 | 5.00 HRS | | 4.64v | 1399 | 5.00 HRS
4.00v | 1270 | 5.50 HRS | | 4.16v | 1267 | 5.50 HRS | | 4.54v | 1373 | 5.50 HRS
3.60v | 1225 | 6.00 HRS | | 3.78v | 1214 | 6.00 HRS | | 4.44v | 1355 | 6.00 HRS
3.40v | 1115 | 6.16 HRS | | 3.40v | 1076 | 6.50 HRS | | 4.32v | 1316 | 6.50 HRS
| | | | | | | | 4.20v | 1281 | 7.00 HRS
| | | | | | | | 3.95v | 1234 | 7.50 HRS
| | | | | | | | 3.53v | 1145 | 8.0 HRS
| | | | | | | | 3.30v | 1086 | 8.16 HRS
Total Runtime: 6 Hours, 10 Minutes | | | | Total Runtime: 6 Hours, 30 Minutes | | | | Total Runtime: 8 Hours, 10 Minutes
Note: AI Thinker board clone - has a distinctive circle dot next to ESP32-CAM text on the PCB. This PCB has horizontal interference lines showing on the camera stream. Made in China. | | | | Note: AI Thinker board clone - board has proper shielding and good quality PCB components with no camera interference. Made in China. | | | | Note: Original AI Thinker board, increased run time due to production quality and components used in manufacture.

Note: All testing done with 4 x Duracell Coppertop AA Batteries. Each cell measured at approximately 1.62v prior to power on. Testing motherboard used was the AUS Precision ESP32-CAM MB Version 6 with a buck/boost voltage regulator fitted.

Phone (AUS): +61 412-701-411 Phone (USA): +1 832-863-0585 www.ausprecision.com.au info@ausprecision.com.au

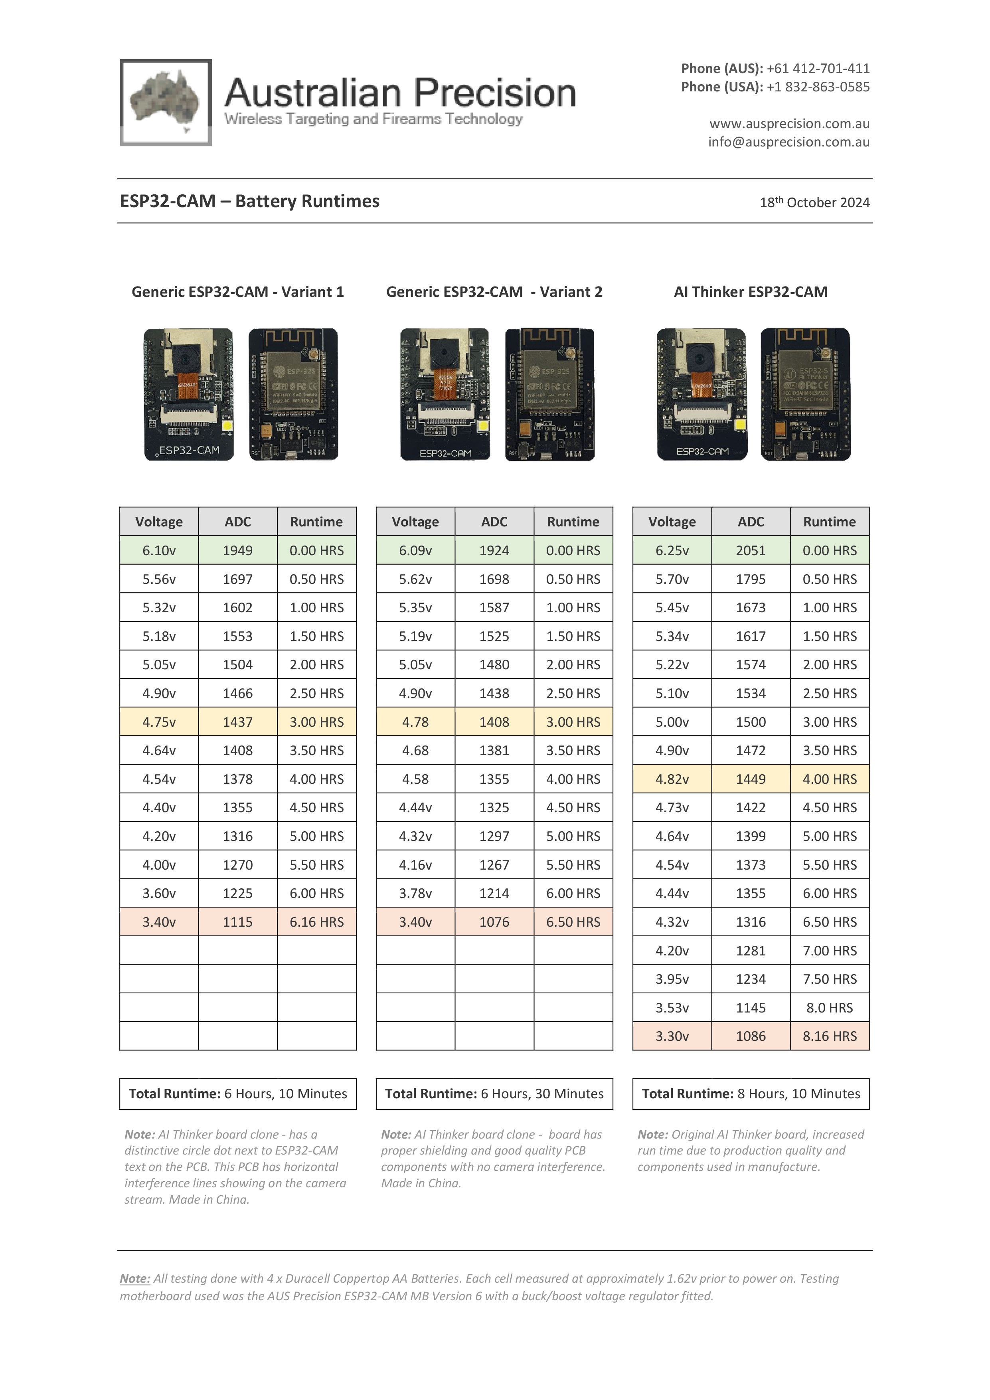
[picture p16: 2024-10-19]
Documentation/AUS Precision - ESP32-CAM - Test Report - Battery Runtime (20241018).png

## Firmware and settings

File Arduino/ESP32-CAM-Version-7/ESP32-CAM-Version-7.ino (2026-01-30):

#include <ArduinoBLE.h>
#include <Arduino.h>
#include <WiFi.h>
#include <WebServer.h>
#include <Update.h>
#include <Ticker.h>
#include <AsyncUDP.h>

#include "html.h"
#include "lib_battery.h"
#include "lib_spiffs.h"
#include "lib_udp.h"
#include "lib_term.h"
#include "lib_wifi.h"
#include "lib_cpu.h"
#include "lib_camera.h"
#include "lib_commands.h"

#include "esp_camera.h"
#include "esp_wifi.h"

#include "ESPTelnet.h"
//#include "printHelpers.h"

#include <uptime.h>
#include <uptime_formatter.h>
#include <string_asukiaaa.h>

#define LED_GRN  14
#define LED_YEL  15
#define LED_RED  13
#define LED_BLU  2

int ledState = LOW;
uint8_t otaDone = 0;

String diagBattery;
float  diagTempCelsius;
String diagUptime;
bool telnetRunning = false;

String diagWiFiCHAN = "4";
String diagWiFiSSID = "apcamera";
String diagWiFiPASS = "tspass2000";
String diagWiFiPOWR = "10";
String diagWiFiPROT = "";

String diagCfgRES = "FRAMESIZE_UXGA";
String diagCfgXCLK = "8";
String diagCfgAEC2 = "1";
String diagVFLIP = "1";
String diagHFLIP = "1";
String diagQUAL = "12";     //10-63 lower number means higher quality

String diagCPU = "240";

WebServer server(8090);
WiFiUDP udpListener;
char packetBuffer[255];

Ticker tkSecond;
Ticker tk_wifi_blink;
Ticker tkUdpSend;

IPAddress temp_IP(192,168,4,255);
IPAddress gateway(192,168,4,1);
IPAddress subnet(255,255,255,0);

void startCameraServer();

ESPTelnet telnet;
IPAddress ip;
uint16_t  port = 23;

void everySecond(){ if (otaDone > 1) { Serial.printf("ota: %d%%\n", otaDone); } }
void timer_wifi_blink() { if (WiFi.softAPgetStationNum() == 0) { if (ledState == LOW) { ledState = HIGH; } else { ledState = LOW; } digitalWrite(LED_BLU, ledState); } else { digitalWrite(LED_BLU, HIGH); } }


void udpSend() { 
  uptime::calculateUptime();
  diagUptime = string_asukiaaa::padStart(String(uptime::getHours()), 2, '0') + "h:" + string_asukiaaa::padStart(String(uptime::getMinutes()), 2, '0') + "m:" + string_asukiaaa::padStart(String(uptime::getSeconds()), 2, '0') + "s";
  
  String udpMessage = "[ESP32-CAM] Uptime: " + diagUptime + " | Res: " + diagCfgRES.substring(10) + " | Clients: " + String(WiFi.softAPgetStationNum()) + " | Batt ADC: " + diagBattery + " (PWR ON)";
  udpMessage = udpMessage + " | CPU: " + diagCPU + "Mhz | " + " WiFi Prot: " + diagWiFiPROT + " | WiFi CH: " + diagWiFiCHAN + " | WiFi TX: " + diagWiFiPOWR.substring(11) + " | XCLK: " + diagCfgXCLK + " | AEC2: " + diagCfgAEC2;
  udpMessage = udpMessage + " | HF: " + diagHFLIP + " | VF: " + diagVFLIP + " | QUAL: " + diagQUAL;
  Serial.print("udpserver_tx: "); udpSendMessage(temp_IP,udpMessage,2090); Serial.println(udpMessage); 
  }

void setupTelnet() { telnet.onConnect(onTelnetConnect); telnet.onConnectionAttempt(onTelnetConnectionAttempt); telnet.onReconnect(onTelnetReconnect); telnet.onDisconnect(onTelnetDisconnect); telnet.onInputReceived(onTelnetInput); Serial.print("telnetserver: "); if (telnet.begin(port)) { Serial.println("running");  }  telnetRunning = true; }
void onTelnetConnect(String ip)           { telnet.println("Starting AP-DOS..."); telnet.println(""); telnet.println(""); telnet.print("C:\\>"); }
void onTelnetDisconnect(String ip)        { Serial.print("telnetserver: "); Serial.print(ip); Serial.println(" disconnected"); }
void onTelnetReconnect(String ip)         { Serial.print("telnetserver: "); Serial.print(ip); Serial.println(" reconnected"); telnet.println(""); telnet.println("Reconnected to AP-DOS Version 1.00"); telnet.println(""); telnet.println("");  telnet.print("C:\\>"); }
void onTelnetConnectionAttempt(String ip) { Serial.print("telnetserver: "); Serial.print(ip); Serial.println(" tried to connect"); }
void onTelnetInput(String str)            {  process_command_tel(str, telnet, diagCfgRES, diagCfgAEC2, diagCfgXCLK, diagQUAL, diagHFLIP, diagVFLIP, diagCPU, diagWiFiPOWR, diagWiFiCHAN, diagWiFiSSID, diagWiFiPASS); }

void webServerInit() {
  server.on("/update", HTTP_POST, []() { handleUpdateEnd(); }, []() { handleUpdate(); } );
  server.serveStatic("/favicon.ico", SPIFFS, "/favicon.ico");
  server.onNotFound([]() { server.send(200, "text/html", indexHtml); });
  server.begin();
  Serial.printf("http_service: %s\n", WiFi.softAPIP().toString().c_str());
}                

void handleUpdateEnd()  { server.sendHeader("Connection", "close"); if (Update.hasError()) { server.send(502, "text/plain", Update.errorString()); } else { server.sendHeader("Refresh", "10"); server.sendHeader("Location", "/"); server.send(307); delay(2000); ESP.restart(); delay(200); } }
void handleUpdate()     { size_t fsize = UPDATE_SIZE_UNKNOWN; if (server.hasArg("size")) { fsize = server.arg("size").toInt(); } HTTPUpload &upload = server.upload(); if (upload.status == UPLOAD_FILE_START) { Serial.printf("Receiving Update: %s, Size: %d\n", upload.filename.c_str(), fsize);    if (!Update.begin(fsize)) { otaDone = 0; Update.printError(Serial); }    } else if (upload.status == UPLOAD_FILE_WRITE) {    if (Update.write(upload.buf, upload.currentSize) != upload.currentSize) {      Update.printError(Serial);    } else {      otaDone = 100 * Update.progress() / Update.size();    }  } else if (upload.status == UPLOAD_FILE_END) {    if (Update.end(true)) {      Serial.printf("Update Success: %u bytes\nRebooting...\n", upload.totalSize); delay(200);   } else {      Serial.printf("%s\n", Update.errorString()); otaDone = 0; }  }}

void setup() {
  Serial.begin(9600); Serial.println(""); Serial.println(""); uptime::calculateUptime(); diagUptime = String(uptime::getHours()) + "H:" + String(uptime::getMinutes()) + "M:" + String(uptime::getSeconds()) + "S";
  
  battery_read_initialization(diagBattery);                                                           // Battery Subsystem Initialization
  spiffs_files_initialization(); listDir(SPIFFS, "/", 1); delay(10);                                  // File System Initialization
  esp32_camera_initialization(diagCfgRES, diagHFLIP, diagVFLIP, diagQUAL, diagCfgAEC2, diagCfgXCLK);  // Camera Subsystem Initialization
  esp32_cpusvc_initialization(diagCPU);                                                               // CPU Subsystem Initialization
  

  wifi_espwifi_initialization(diagWiFiPOWR, diagWiFiSSID, diagWiFiPASS, diagWiFiCHAN, diagWiFiPROT);  // Wireless Subsystem Initialization

  // Web Server Initialization, Timer Initialization, UDP Initialization and Camera Server Intitialization
  webServerInit(); setupTelnet(); tkSecond.attach(1, everySecond);  tk_wifi_blink.attach(0.5, timer_wifi_blink);  tkUdpSend.attach(5, udpSend); udpListener.begin(2090);
  Serial.println("udpserver   : UDP Server Initialized!");
  Serial.println("system_stats: Initialization Complete!");
  Serial.println("cameraserver: Camera Server Starting!");
  startCameraServer();
}

void loop() {
  server.handleClient();
  telnet.loop();
  
  int packetSize = udpListener.parsePacket();
  if (packetSize) { int len = udpListener.read(packetBuffer, 255); if (len >= 5) {  process_command_udp(len, packetBuffer, udpListener, diagCfgRES, diagCfgAEC2, diagCfgXCLK, diagQUAL, diagHFLIP, diagVFLIP, diagCPU, diagWiFiPOWR, diagWiFiCHAN, diagWiFiSSID, diagWiFiPASS);    }  }
}

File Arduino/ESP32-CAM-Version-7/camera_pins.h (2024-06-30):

#if defined(CAMERA_MODEL_AI_THINKER)
#define PWDN_GPIO_NUM  32
#define RESET_GPIO_NUM -1
#define XCLK_GPIO_NUM  0
#define SIOD_GPIO_NUM  26
#define SIOC_GPIO_NUM  27

#define Y9_GPIO_NUM    35
#define Y8_GPIO_NUM    34
#define Y7_GPIO_NUM    39
#define Y6_GPIO_NUM    36
#define Y5_GPIO_NUM    21
#define Y4_GPIO_NUM    19
#define Y3_GPIO_NUM    18
#define Y2_GPIO_NUM    5
#define VSYNC_GPIO_NUM 25
#define HREF_GPIO_NUM  23
#define PCLK_GPIO_NUM  22

// 4 for flash led or 33 for normal led
#define LED_GPIO_NUM   4

#else
#error "Camera model not selected"
#endif

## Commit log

2024-06-30 Arduino Code - Initial Release
    The initial release of the Arduino code for the ESP32-CAM Target Camera. Features include OTA, reading the battery level upon startup before WiFi and camera initialize. Battery is ready before this as when WiFi is initialized, the ADC inputs can no longer be used.
    [config.txt]
2024-07-02 3D Printed Parts - Initial Release
    3D Printed parts for the ESP32 Target Camera.
    [ESP32 Target Camera - Battery Section v4 - 20240525.stl, ESP32 Target Camera - Holder - Antenna v2 - 20240525.stl, ESP32 Target Camera - Holder - Nut Holder v4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]
2024-07-02 Initial Release - Testing - Visual Basic
    Visual Basic UWP Code to simply test the MJPEG image stream from the ESP32-CAM. This will be expanded in functionality / functions and will also have UDP protocol testing included as well.
2024-07-12 Added PCB, Rename of Folders, Update of UWP
    Rename of 3D Printing Folders
    Added PCB files (Gerber, Drill)
    Update of UWP Testing VB to allow connection to ESP32-CAM MJPEG stream and AUS Precision simulated MJPEG Stream.
    [ESP32 Target Camera - Battery Section v4 - 20240525.stl, ESP32 Target Camera - Holder - Antenna v2 - 20240525.stl, ESP32 Target Camera - Holder - Nut Holder v4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]
2024-07-15 Manufacturing - PCB
    Updated PCB board designs, added renderings of PCB's, added README file containing information about PCB's and manufacture.
2024-07-29 Updated 3D Parts for Printing
    3D printed parts for the target camera, .STL conversion is in mm. Locating blocks for separating the battery board from the main board have been added.
    [ESP32 Target Camera - Battery Section v4 - 20240525.stl, ESP32 Target Camera - Holder - Antenna v2 - 20240525.stl, ESP32 Target Camera - Holder - Nut Holder v4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]
2024-07-30 Arduino Code - Update
    Update for boot sequence to flash all the LED lights as part of a diagnostic measure.
2024-07-30 Manufacturing - Parts List - Initial Release
    Initial release of the parts list, this includes all the components to build the ESP32-CAM Target Camera.
    [Parts List - Version 1 - 20240729.xlsx]
2024-08-09 Arduino Code - Stable Release
    Stable Release of the Version 1 code for Arduino with basic features - MJPEG streaming and OTA updates are enabled and working. This release will work with the Visual Studio Project/Code - UWP-Testin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
2024-08-13 Arduino Code - Beta Release
    UDP Messaging Protocol Introduced for sending and receiving data. Telnet Server implemented with DOS style interface (work in progress). Basic camera configuration files exist under SPIFFS for storin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
2024-08-13 Manufacturing - 3D Printing
    Added a 3D printed tool for holding all the header pins in place when soldering.
    [Tool - Header Pin Holder for Solder - Version 1 - 20240730.stl]
2024-08-13 Manufacturing - Tools Required (Work in Progress)
    Work in progress, but a basic list of the tools required for the project.
    [Tools Required - Version 1 - 20240730.xlsx]
2024-08-13 Visual Basic Code - Beta Release
    Added support for UDP sending and receiving of messages. Camera configuration commands can be sent via an input box. UDP processing of commands will change camera settings on the fly. Basic camera st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
2024-09-01 Manufacturing - PCB
    Update to include a 5v regulated power supply and also a bypass jumper for the 5v regulator.
2024-09-01 Arduino Code - Stable Release
    Introduces Telnet Functionality.
2024-09-01 Arduino Code - Beta Release
    Full featured telnet interface, introduces ability to read/write to configuration files. Reads configuration files upon startup.
2024-09-02 Manufacturing - PCB (Regulated 5v)
    Updated design to include a 5v regulator chip and also a 5v regulator bypass jumper if you do not wish to use the regulator chip.
2024-09-17 Arduino Code - Beta Release
    Updated firmware bin file for R3, new version 4R1 which has full implementation of AP-DOS 1.0.
2024-09-17 Manufacturing - 3D Printing
    Update for locating blocks for the PCB sandwich, 2 versions 6.3mm in height and 6.5mm in height. Depending on your 3D printer, you might need to use one or the other for different tolerances to eliminate any movement inside the enclosure.
    [ESP32 Target Camera - Locating Block - v1 - 20240613.stl, Locating Blocks x 4 - Version 1 - 6.3mm - 20240729.stl, Locating Blocks x 4 - Version 1 - 6.8mm - 202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]
2024-09-17 Visual Basic Code - NET4.0 - Beta Release
    GitHub modification to folder structure. Camera stream now stretches to the window size. More diagnostic information is now displayed on screen and also checks Wi-Fi signal strength.
2024-09-17 Manufacturing - PCB (5v Regulated)
    Update for the motherboard PCB with a 5v Regulator, the previous design had errors in track layout. This has corrected those errors.
2024-10-19 Test Reports
    Test Reports - Battery Runtime Report for the AI Thinker ESP32-CAM Board and 2 ESP32-CAM variant boards that were manufactured in China.
2024-10-19 Arduino Code - Beta Release
    NETWORKS and README files for the AP-DOS operating system.
2024-12-16 Removal of old Arduino Builds
2024-12-16 Arduino Code - Beta Release
2024-12-16 Arduino Code - Stable Release
2026-01-30 Update to include Versions 6 and 7 of the ESP32-CAM Target Camera Operating System
    [Parts List - Version 1 - 20241218 - No Antenna.xlsx, Parts List - Version 2 - 20250729 - No Antenna.xlsx, config.txt]
